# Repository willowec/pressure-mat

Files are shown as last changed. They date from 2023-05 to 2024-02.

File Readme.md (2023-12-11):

# Pressure Mat Project

This git repository contains all the code developed for the Electrical and Computer Engineering Capstone project of Evan Desmond and Willow Cunningham at the University of Maine, Orono. 

## The Mat

The pressure sensing mat uses the intersections between rows and columns of copper tape separated by velostat to form resistive pressure sensors. The mat has 28 rows and 56 columns, for a total of 1568 sensors at a resolution of 1cm^2.

## The PCB

Schematics for the PCB are in ```/board_kicad``` A render of the pcb is shown below.

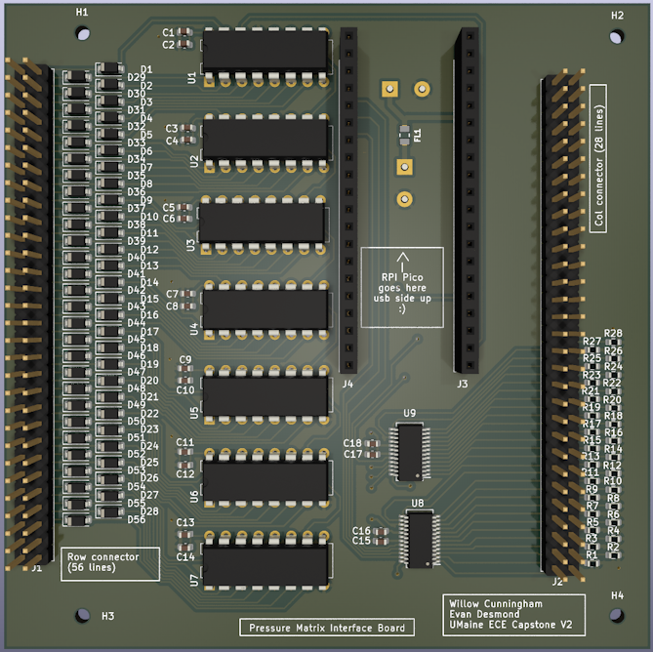
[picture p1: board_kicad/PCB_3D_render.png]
PCB 3D Render


## The Code

Code for the project is split into two primary parts: embedded side and host side.

### Embedded Code

The code that the RPI Pico runs is in the ```/board_code``` directory. It is responsible for controlling the ADCs and shift registers on the PCB in order to read the pressure sensors in the mat, and transmitting the mat data over USB serial to the connected host computer.

### Host Code

The python program in ```/GUI```  is used to view data recorded and transmitted by the interface board.

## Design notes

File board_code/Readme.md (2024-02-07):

# Board Side Code

This directory holds the embedded code that runs on the RPi Pico responsible for interfacing with the PMI PCB's ADC's and communicating with the connected laptop.

## Usage

The embedded code has three build targets: board_v1, board_v2, and board_v2_slow

 - board_v1.uf2: Designed to run on the v1 version of the PCB. single core, ~1Hz sample rate.
 - board_v2.uf2: Designed to run on the v2 version of the PCB. dual core, ~49Hz sample rate (rate limited by the computer's ability to handle serial communications).
 - board_v2_slow.uf2: Designed to run on the v2 version of the PCB. dual core, rate limited to ~8Hz sample rate.

### Build the code:
1. Install the rpi pico sdk somewhere on your computer: [pico-sdk](https://github.com/raspberrypi/pico-sdk)
2. Enter a linux environment (WSL)
3. 
        mkdir build
        cd build
        export PICO_SDK_PATH=../relative/path/to/the/cloned/directory/named/pico-sdk
        cmake ..
        make

4. Copy the uf2 file of the build target you want to program the pico with to the pico's flash to program it.

### Communicating With The Board

After connecting the programmed RPi Pico to your computer via usb, it can be talked to over serial. The board can understand the following commands:

1. PRINT_INFO:

    message:

        print_info
        
    response:

    The board prints a short message identifying its software version and then awaits further commands.

2. GET_CAL_VALS:

    message:

        get_cal_vals
        
    response:

    The board reads the mat in full once and transmits the collected data over serial before waiting for further commands. See [Mat Data Transmission Format](#mat-data-transmission-format) for more information.

3. START_READING:

    message:

        start_reading
        
    response:

    The board stops listening to commands and begins reading and transmitting sensor values over serial. The board will continue to read and transmit mat data until unpowered. See [Mat Data Transmission Format](#mat-data-transmission-format) for more information.

### Mat Data Transmission Format

The board code is designed to interface a 28x56 array of resistive pressure sensors, where data from each sensor is recorded by an 8-bit ADC. Each time the mat is read, 1,568 8-bit values must be transmitted over serial. This transmission is performed in accordance with the following format, where bytes 1-4 are the verification sequence and bytes 5-1572 are the values that the ADCs on the PCB recorded for each sensor:

        byte number:           1       2       3       4       5       6               1571    1572
        character value:       0xFF    0xFE    0xFE    0xFF    0xXX    0xXX    ...     0xXX    0xXX

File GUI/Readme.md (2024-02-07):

# GUI

The GUI for communicating with the PMI board. Developed for python 3.10.6.

A screenshot of the GUI loading a past session

## Usage

1. Install dependancies using the following command:

		pip install -r requirements.txt

2. Run the GUI app using python

		python GUI.py

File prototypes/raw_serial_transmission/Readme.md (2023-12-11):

# Prototype to test the feasability of sending raw data over serial

Instead of encoding data into hexadecimal for transmission from pico to pc, it should be possible to send raw data over serial. This directory is a prototype which tests that theory.

The result of this test is that yes, data can be transmitted over serial much more efficiently than by encoding to hexadecimal and decoding it on the reciever.

[https://datasheets.raspberrypi.com/pico/getting-started-with-pico.pdf](https://datasheets.raspberrypi.com/pico/getting-started-with-pico.pdf)

requires that the pico_sdk repository is cloned on your computer

## building:

    mkdir build
    cd build
    export PICO_SDK_PATH=../relative/path/to/the/cloned/directory/named/pico-sdk
    cmake ..
    make

Then just copy the UF2 file onto the pico's flash

## Running

Plug the pico into your pc, then run

    python reciever.py "COMX"

where COMX should be the com port your pico shows up on (COM1, COM2, COM3, etc)

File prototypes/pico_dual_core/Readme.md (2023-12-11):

# Custom multicore for RP2040

This is a small multicore library for the raspberry pi pico. It is heavily based on the built-in multicore library that is provided by the Raspberry Pi Foundation. This library is used by the embedded code for the pressure mat project in ```/board_code```.

Reference:

[https://datasheets.raspberrypi.com/pico/getting-started-with-pico.pdf](https://datasheets.raspberrypi.com/pico/getting-started-with-pico.pdf)

requires that the pico_sdk repository is cloned on your computer

## building:

    mkdir build
    cd build
    export PICO_SDK_PATH=../relative/path/to/the/cloned/directory/named/pico-sdk
    cmake ..
    make

Then just copy the UF2 file onto the pico's flash

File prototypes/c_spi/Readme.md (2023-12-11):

# C spi multicore

this is an example of running an spi client (slave) on one core and an spi controller (master) on the other core

[https://datasheets.raspberrypi.com/pico/getting-started-with-pico.pdf](https://datasheets.raspberrypi.com/pico/getting-started-with-pico.pdf)

requires that the pico_sdk repository is cloned onto your computer

spi tutorial: (page 152)
[https://datasheets.raspberrypi.com/pico/raspberry-pi-pico-c-sdk.pdf](https://datasheets.raspberrypi.com/pico/raspberry-pi-pico-c-sdk.pdf)

## hardware:

Connect the two spi cahnnels absed on the following image

image of a pico with the two spi channels connected

## building:

    mkdir build
    cd build
    export PICO_SD_PATH=../relative/path/to/the/cloned/directory/named/pico-sdk
    cmake ..
    make

Then just copy the UF2 file onto the pico's flash

## build error: wrong compiler

If you compile the project and get a ton of errors about assembly instructions not being recognized, it is likely because the wrong compiler is being used. To fix this, cd into build and remove CMakeCache.txt, then rebuild:

    cd build
    rm CMakeCache.txt
    cmake ..
    make

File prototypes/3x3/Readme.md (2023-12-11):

# 3x3 mat prototype using an RPI pico

## Usage
1. Flash the board using rshell https://github.com/dhylands/rshell or any other means  
```
>rshell
>cp board.py /pyboard/main.py
```
2. Unpower and re-connect the pico board to restart it
3. Run the host script using ```py .\host.py```
4. Enter the com port the pico is connected to and hit connect

## Schematic
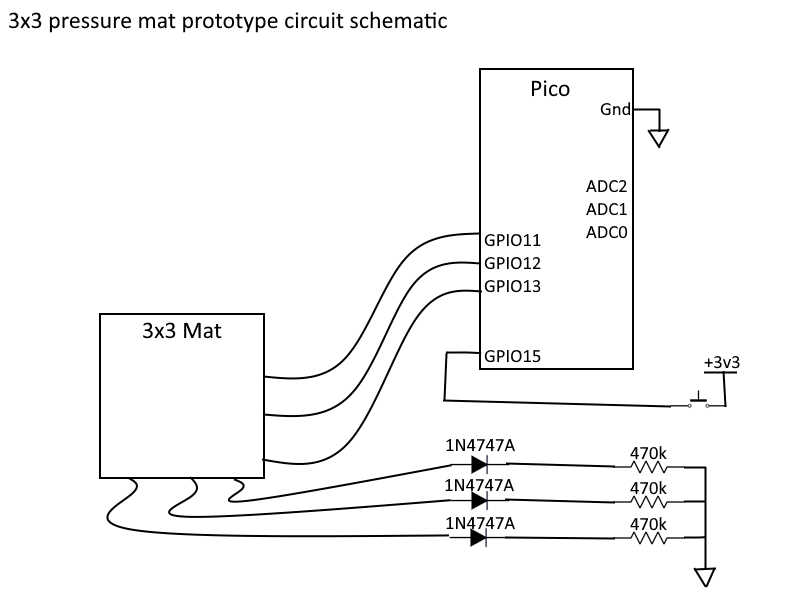
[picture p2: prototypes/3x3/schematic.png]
Overall Schematic


## Constructed Circuit
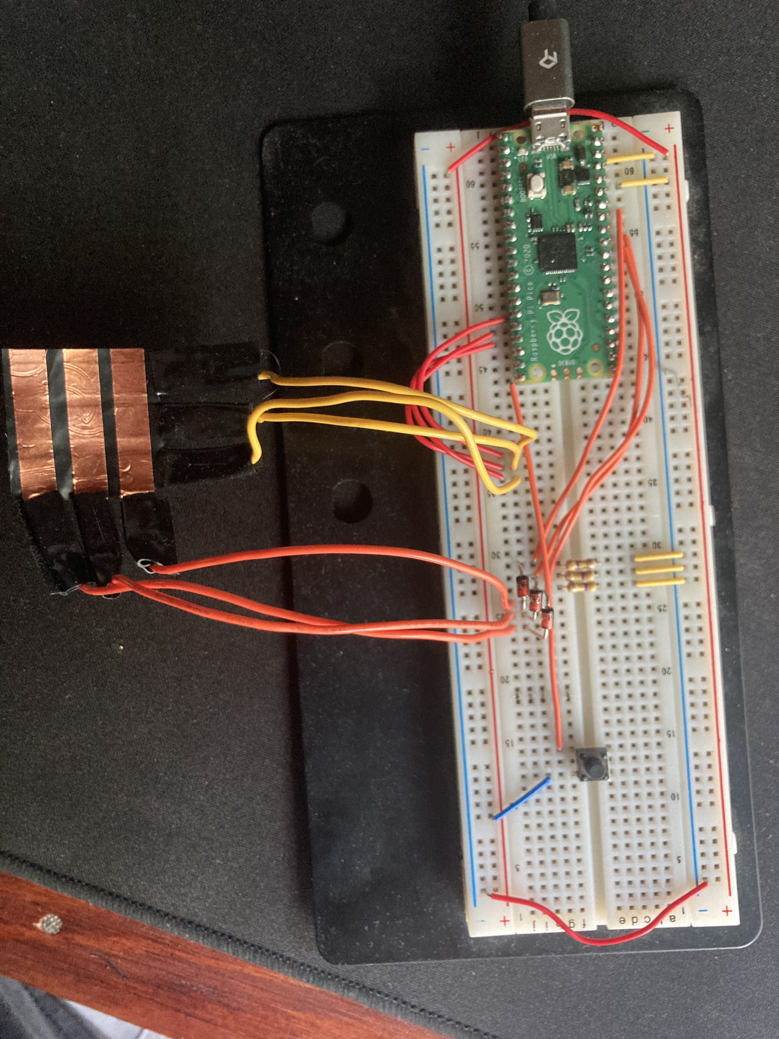
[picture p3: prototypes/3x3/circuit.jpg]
Photo of the circuit on a breadboard


## Programming the RPI Pico

Getting started (on Windows):

1. Download the micropython UF2 file from the RPI website and install it on the board:

    https://www.raspberrypi.com/documentation/microcontrollers/micropython.html

2. Install Rshell

### Copying code to the RPI Pico

1. run rshell:

    On my machine, the pico connects to COM3. You can find what port the pico is connected on by looking for it under the 'Ports (COM & LPT)' dropdown in the Device Manager on Windows

        rshell --buffer-size=512 -p COM3

2. in rshell, copy the python file that you want the pico to run to /pyboard/main.py

        cp pythonfile.py /pyboard/main.py

3. disconnect the pico from power and reconnect it. Your code should then run when the pi powers on.

## Resetting the RPI Pico

If you flash the pico with some code that takes permanent control of its serial port, you will need to clear the flash of the pico to reset it. A great example of code like this is the 3x3 prototype's [board.py file](./prototypes/3x3/board.py). Lets try to avoid writing code like this for the final project.

1. Download the flash_nuke UF2 file: [https://datasheets.raspberrypi.com/soft/flash_nuke.uf2](https://datasheets.raspberrypi.com/soft/flash_nuke.uf2)
2. Connect the pico to your laptop while holding the BOOTSEL button down
3. Copy the flask_nuke.uf2 file onto the pico storage device. This will reset its flash and reboot the pico. Do not disconnect power during this process.
4. Copy the micropython UF2 file onto the pico to re-flash it.

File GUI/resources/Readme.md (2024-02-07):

# PMI System Resources

This directory contains assorted scripts and resources used by the GUI for communicating with the PMI, and developers for collecting and plotting data from the PMI.

### averaged_calibration_curves.npy

[averaged_calibration_curves.npy](averaged_calibration_curves.npy) is a numpy array containing calibration curves to be loaded by the GUI program. The file is generated by [generate_cal_curves.py](generate_cal_curves.py).

### default_calibration_curves.npy

[default_calibration_curves.npy](default_calibration_curves.npy) is a numpy array containing calibration curves to be loaded by the GUI program. The file is generated by [generate_cal_curves.py](generate_cal_curves.py).

### calibrate_individual_sensor.py

[calibrate_individual_sensor.py](calibrate_individual_sensor.py) is a CLI tool for getting calibration data from a small number of sensors on the mat manually. This tool did not end up being used in the final version of the project.

### get_mat_data.py

[get_mat_data.py](get_mat_data.py) is a CLI tool used for collecting raw data from the PMI.

### generate_cal_curves.py

[generate_cal_curves.py](generate_cal_curves.py) generates caibration curves for the GUI based on data collected by [get_mat_data.py](get_mat_data.py).

### plot_readings.py

[plot_readings.py](plot_readings.py) produces various useful plots from the data collected by [get_mat_data.py](get_mat_data.py).

### test_matspeed.py

[test_matspeed.py](test_matspeed.py) tests the speed at which the PMI can collect and transmit data when the GUI is not slowing it down.

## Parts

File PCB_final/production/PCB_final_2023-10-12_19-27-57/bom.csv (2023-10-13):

Designator | Footprint | Quantity | Value | LCSC Part #
C1, C11, C13, C3, C5, C7, C9 | 603 | 7 | 1uF
C10, C12, C14, C17, C2, C4, C6, C8 | 603 | 8 | 0.1uF
C15, C16 | 603 | 2 | .1uF
D1, D10, D11, D12, D13, D14, D15, D16, D17, D18, D19, D2, D20, D21, D22, D23, D24, D25, D26, D27, D28, D29, D3, D30, D31, D32, D33, D34, D35, D36, D37, D38, D39, D4, D40, D41, D42, D43, D44, D45, D46, D47, D48, D49, D5, D50, D51, D52, D53, D54, D55, D56, D6, D7, D8, D9 | D_SOD-123 | 56 | MMSD4148
R1, R10, R11, R12, R13, R14, R15, R16, R17, R18, R19, R2, R20, R21, R22, R23, R24, R25, R26, R27, R28, R29, R3, R4, R5, R6, R7, R8, R9 | 603 | 29 | 100k
U10 | SOT-23-5 | 1 | LM321
U8, U9 | SSOP-24_3.9x8.7mm_P0.635mm | 2 | MAX11643EEG

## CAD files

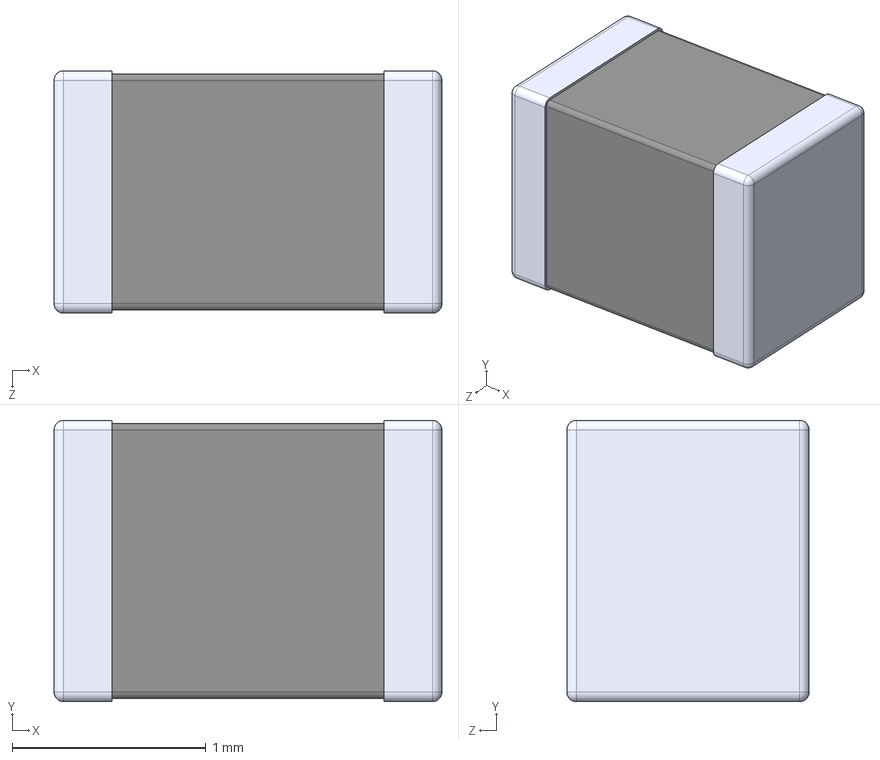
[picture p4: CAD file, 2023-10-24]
board_kicad/kicad_symbol_lib/BLM21BD272SN1L/BLM21BD272SN1L.step
2.00 x 1.45 x 1.25 mm

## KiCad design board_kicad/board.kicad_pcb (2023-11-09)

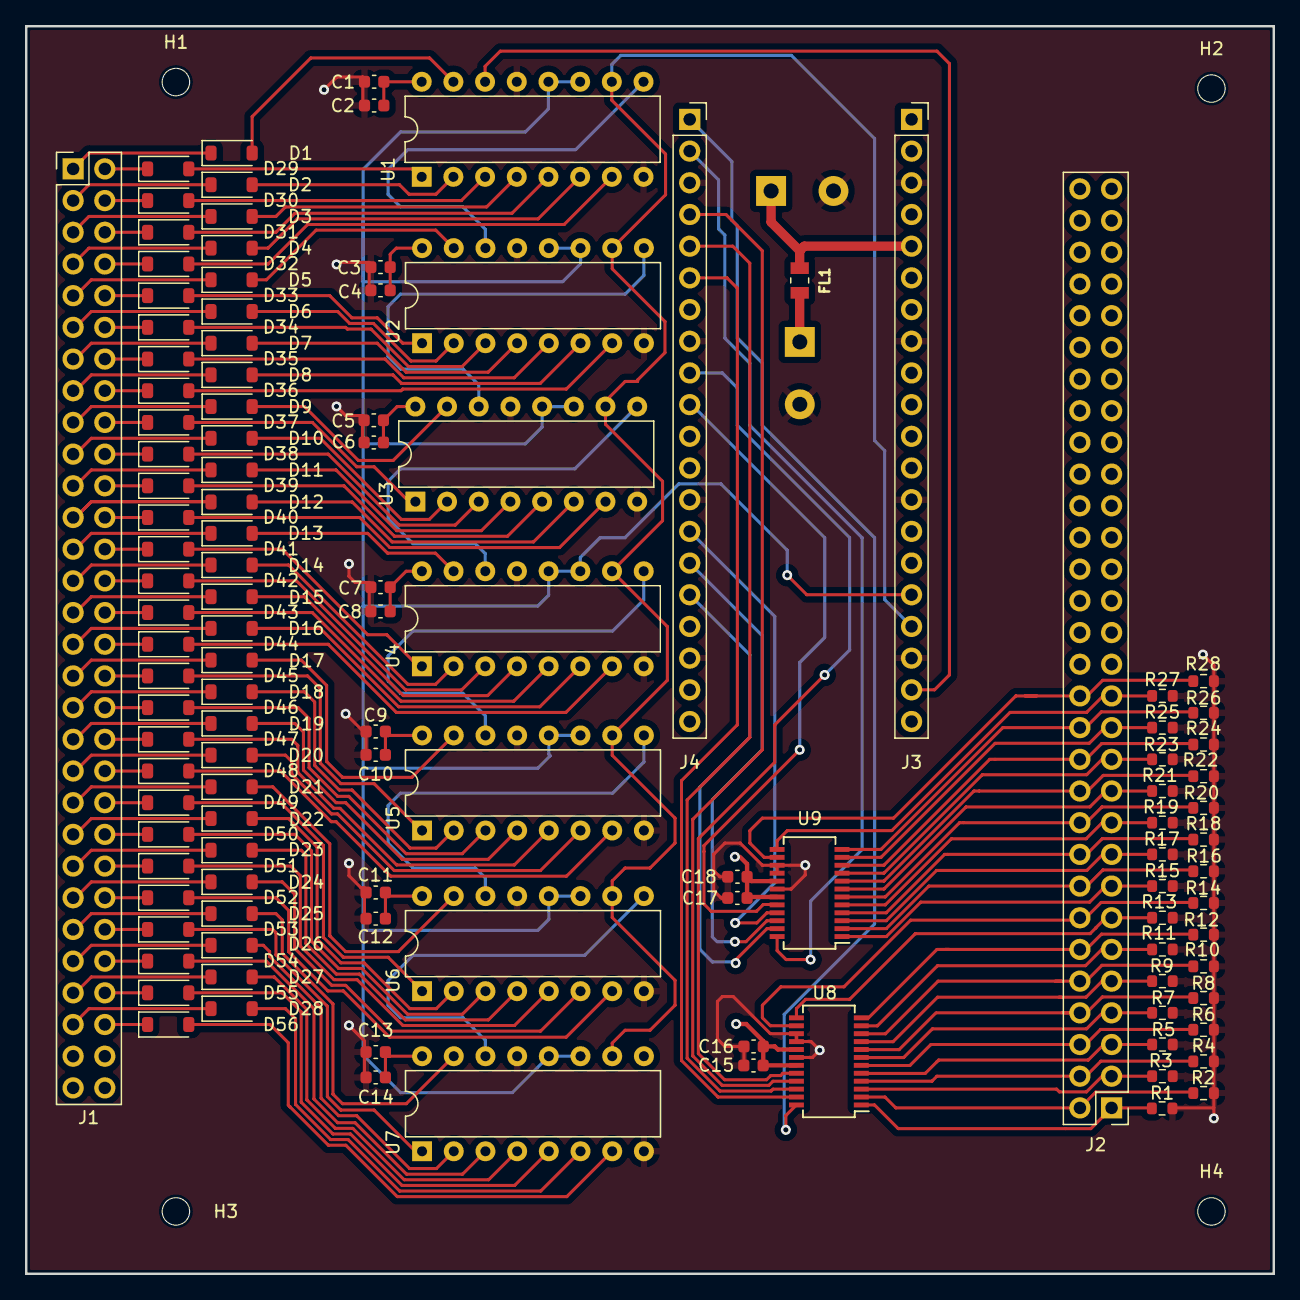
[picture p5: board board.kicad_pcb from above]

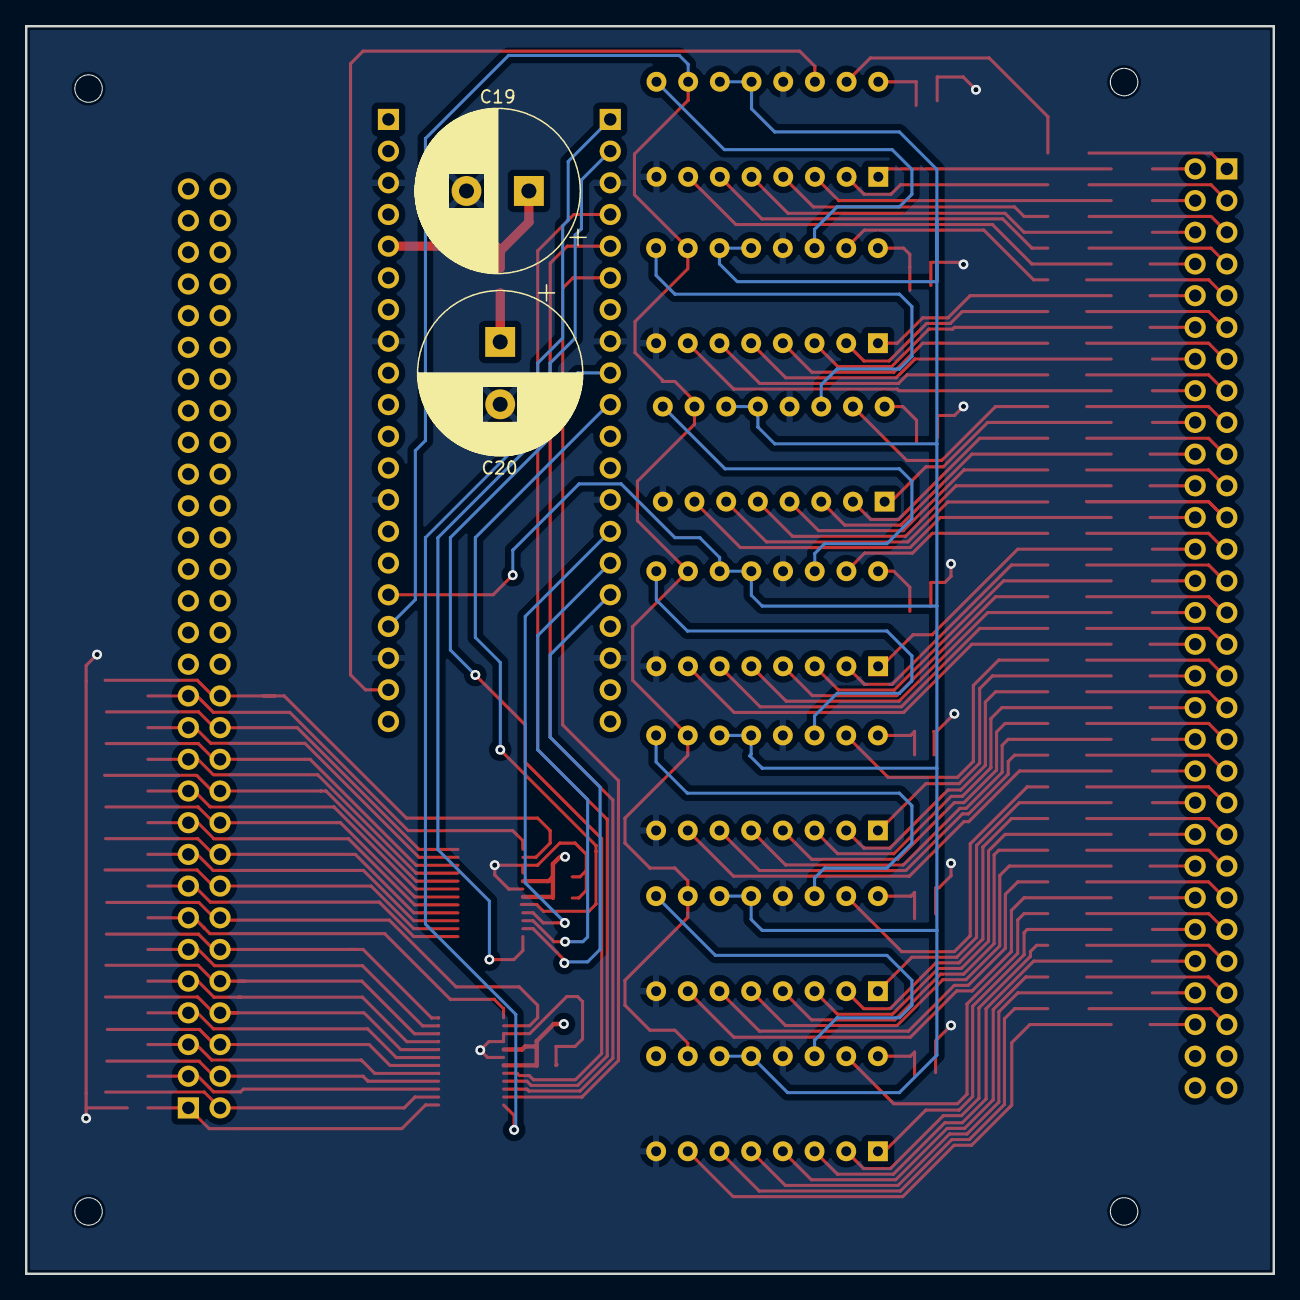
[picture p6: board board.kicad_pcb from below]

Board: 4 copper layers, 100.0 x 100.0 mm, 122 parts (2 on the bottom side), 162 nets.

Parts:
C1, C3, C5, C7, C9, C11, C13: 1uF; C_0603_1608Metric
C2, C4, C6, C8, C10, C12, C14: 0.1uF; C_0603_1608Metric
C15, C16, C17, C18: .1uF; C_0603_1608Metric
C19, C20: 4.7mF; CP_Radial_D13.0mm_P5.00mm
D1, D2, D3, D4, D5, D6, D7, D8, D9, D10, D11, D12, D13, D14, D15, D16, D17, D18, D19, D20, D21, D22, D23, D24, D25, D26, D27, D28, D29, D30, D31, D32, D33, D34, D35, D36, D37, D38, D39, D40, D41, D42, D43, D44, D45, D46, D47, D48, D49, D50, D51, D52, D53, D54, D55, D56: MMSD4148; D_SOD-123
FL1: BLM21BD272SN1L; BEADC2012X145N
H1, H2, H3, H4: MountingHole; MountingHole_2.2mm_M2
J1: 02x30_Shift_Register_Connector; PinHeader_2x30_P2.54mm_Vertical
J2: 02x30_ADC_Connector; PinHeader_2x30_P2.54mm_Vertical
J3: PicoPinSocketB; PinSocket_1x20_P2.54mm_Vertical
J4: PicoPinSocketA; PinSocket_1x20_P2.54mm_Vertical
R1, R2, R3, R4, R5, R6, R7, R8, R9, R10, R11, R12, R13, R14, R15, R16, R17, R18, R19, R20, R21, R22, R23, R24, R25, R26, R27, R28: 100k; R_0603_1608Metric
U1, U2, U3, U4, U5, U6, U7: 74HC595; DIP-16_W7.62mm
U8, U9: MAX11643EEG; SSOP-24_3.9x8.7mm_P0.635mm

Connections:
3V3_Pico: C19.1, FL1.1, J3.5
+3V3: C1.1, C2.1, C3.1, C4.1, C5.1, C6.1, C7.1, C8.1, C9.1, C10.1, C11.1, C12.1, C13.1, C14.1, C15.1, C16.1, C17.1, C18.1, C20.1, FL1.2, U1.16 (VCC), U2.16 (VCC), U3.16 (VCC), U4.16 (VCC), U5.16 (VCC), U6.16 (VCC), U7.16 (VCC), U8.17 (REF), U8.19 (VDD), U9.17 (REF), U9.19 (VDD)
/Interface Board/ADC1_EOC: J4.1, U8.24 (EOC)
/Interface Board/ADC2_EOC: J4.2, U9.24 (EOC)
/Interface Board/ADC_IN1: J2.1, R1.1, U8.1 (AIN0)
/Interface Board/ADC_IN2: J2.2, R2.1, U8.2 (AIN1)
/Interface Board/ADC_IN3: J2.3, R3.1, U8.3 (AIN2)
/Interface Board/ADC_IN4: J2.4, R4.1, U8.4 (AIN3)
/Interface Board/ADC_IN5: J2.5, R5.1, U8.5 (AIN4)
/Interface Board/ADC_IN6: J2.6, R6.1, U8.6 (AIN5)
/Interface Board/ADC_IN7: J2.7, R7.1, U8.7 (AIN6)
/Interface Board/ADC_IN8: J2.8, R8.1, U8.8 (AIN7)
/Interface Board/ADC_IN9: J2.9, R9.1, U8.9 (AIN8)
/Interface Board/ADC_IN10: J2.10, R10.1, U8.10 (AIN9)
/Interface Board/ADC_IN11: J2.11, R11.1, U8.11 (AIN10)
/Interface Board/ADC_IN12: J2.12, R12.1, U8.12 (AIN11)
/Interface Board/ADC_IN13: J2.13, R13.1, U8.13 (AIN12)
/Interface Board/ADC_IN14: J2.14, R14.1, U8.14 (AIN13)
/Interface Board/ADC_IN15: J2.15, R15.1, U9.1 (AIN0)
/Interface Board/ADC_IN16: J2.16, R16.1, U9.2 (AIN1)
/Interface Board/ADC_IN17: J2.17, R17.1, U9.3 (AIN2)
/Interface Board/ADC_IN18: J2.18, R18.1, U9.4 (AIN3)
/Interface Board/ADC_IN19: J2.19, R19.1, U9.5 (AIN4)
/Interface Board/ADC_IN20: J2.20, R20.1, U9.6 (AIN5)
/Interface Board/ADC_IN21: J2.21, R21.1, U9.7 (AIN6)
/Interface Board/ADC_IN22: J2.22, R22.1, U9.8 (AIN7)
/Interface Board/ADC_IN23: J2.23, R23.1, U9.9 (AIN8)
/Interface Board/ADC_IN24: J2.24, R24.1, U9.10 (AIN9)
/Interface Board/ADC_IN25: J2.25, R25.1, U9.11 (AIN10)
/Interface Board/ADC_IN26: J2.26, R26.1, U9.12 (AIN11)
/Interface Board/ADC_IN27: J2.27, R27.1, U9.13 (AIN12)
/Interface Board/ADC_IN28: J2.28, R28.1, U9.14 (AIN13)
/Interface Board/CS0: J4.9, U8.20 (CS)
/Interface Board/CS1: J4.10, U9.20 (CS)
/Interface Board/SER5: U4.9 (QH'), U5.14 (SER)
/Interface Board/SH_CLK: J3.16, U1.11 (SRCLK), U1.12 (RCLK), U2.11 (SRCLK), U2.12 (RCLK), U3.11 (SRCLK), U3.12 (RCLK), U4.11 (SRCLK), U4.12 (RCLK), U5.11 (SRCLK), U5.12 (RCLK), U6.11 (SRCLK), U6.12 (RCLK), U7.11 (SRCLK), U7.12 (RCLK)
/Interface Board/SH_CLR: J3.17, U1.10 (~SRCLR), U2.10 (~SRCLR), U3.10 (~SRCLR), U4.10 (~SRCLR), U5.10 (~SRCLR), U6.10 (~SRCLR), U7.10 (~SRCLR)
/Interface Board/SH_SERIN: J3.19, U1.14 (SER)
/Interface Board/SOUT1: D1.2 (A), U1.15 (QA)
/Interface Board/SOUT2: D29.2 (A), U1.1 (QB)
/Interface Board/SOUT3: D2.2 (A), U1.2 (QC)
/Interface Board/SOUT4: D30.2 (A), U1.3 (QD)
/Interface Board/SOUT5: D3.2 (A), U1.4 (QE)
/Interface Board/SOUT6: D31.2 (A), U1.5 (QF)
/Interface Board/SOUT7: D4.2 (A), U1.6 (QG)
/Interface Board/SOUT8: D32.2 (A), U1.7 (QH)
/Interface Board/SOUT9: D5.2 (A), U2.15 (QA)
/Interface Board/SOUT10: D33.2 (A), U2.1 (QB)
/Interface Board/SOUT11: D6.2 (A), U2.2 (QC)
/Interface Board/SOUT12: D34.2 (A), U2.3 (QD)
/Interface Board/SOUT13: D7.2 (A), U2.4 (QE)
/Interface Board/SOUT14: D35.2 (A), U2.5 (QF)
/Interface Board/SOUT15: D8.2 (A), U2.6 (QG)
/Interface Board/SOUT16: D36.2 (A), U2.7 (QH)
/Interface Board/SOUT17: D9.2 (A), U3.15 (QA)
/Interface Board/SOUT18: D37.2 (A), U3.1 (QB)
/Interface Board/SOUT19: D10.2 (A), U3.2 (QC)
/Interface Board/SOUT20: D38.2 (A), U3.3 (QD)
/Interface Board/SOUT21: D11.2 (A), U3.4 (QE)
/Interface Board/SOUT22: D39.2 (A), U3.5 (QF)
/Interface Board/SOUT23: D12.2 (A), U3.6 (QG)
/Interface Board/SOUT24: D40.2 (A), U3.7 (QH)
/Interface Board/SOUT25: D13.2 (A), U4.15 (QA)
/Interface Board/SOUT26: D41.2 (A), U4.1 (QB)
/Interface Board/SOUT27: D14.2 (A), U4.2 (QC)
/Interface Board/SOUT28: D42.2 (A), U4.3 (QD)
/Interface Board/SOUT29: D15.2 (A), U4.4 (QE)
/Interface Board/SOUT30: D43.2 (A), U4.5 (QF)
/Interface Board/SOUT31: D16.2 (A), U4.6 (QG)
/Interface Board/SOUT32: D44.2 (A), U4.7 (QH)
/Interface Board/SOUT33: D17.2 (A), U5.15 (QA)
/Interface Board/SOUT34: D45.2 (A), U5.1 (QB)
/Interface Board/SOUT35: D18.2 (A), U5.2 (QC)
/Interface Board/SOUT36: D46.2 (A), U5.3 (QD)
/Interface Board/SOUT37: D19.2 (A), U5.4 (QE)
/Interface Board/SOUT38: D47.2 (A), U5.5 (QF)
/Interface Board/SOUT39: D20.2 (A), U5.6 (QG)
/Interface Board/SOUT40: D48.2 (A), U5.7 (QH)
/Interface Board/SOUT41: D21.2 (A), U6.15 (QA)
/Interface Board/SOUT42: D49.2 (A), U6.1 (QB)
/Interface Board/SOUT43: D22.2 (A), U6.2 (QC)
/Interface Board/SOUT44: D50.2 (A), U6.3 (QD)
/Interface Board/SOUT45: D23.2 (A), U6.4 (QE)
/Interface Board/SOUT46: D51.2 (A), U6.5 (QF)
/Interface Board/SOUT47: D24.2 (A), U6.6 (QG)
/Interface Board/SOUT48: D52.2 (A), U6.7 (QH)
/Interface Board/SOUT49: D25.2 (A), U7.15 (QA)
/Interface Board/SOUT50: D53.2 (A), U7.1 (QB)
/Interface Board/SOUT51: D26.2 (A), U7.2 (QC)
/Interface Board/SOUT52: D54.2 (A), U7.3 (QD)
/Interface Board/SOUT53: D27.2 (A), U7.4 (QE)
/Interface Board/SOUT54: D55.2 (A), U7.5 (QF)
/Interface Board/SOUT55: D28.2 (A), U7.6 (QG)
/Interface Board/SOUT56: D56.2 (A), U7.7 (QH)
/Interface Board/SPI0_RX: J4.6, U8.23 (DOUT)
/Interface Board/SPI0_SCK: J4.4, U8.21 (SCLK)
/Interface Board/SPI0_TX: J4.5, U8.22 (DIN)
/Interface Board/SPI1_RX: J4.16, U9.23 (DOUT)
/Interface Board/SPI1_SCK: J4.14, U9.21 (SCLK)
/Interface Board/SPI1_TX: J4.15, U9.22 (DIN)
GND: C1.2, C2.2, C3.2, C4.2, C5.2, C6.2, C7.2, C8.2, C9.2, C10.2, C11.2, C12.2, C13.2, C14.2, C15.2, C16.2, C17.2, C18.2, C19.2, C20.2, J3.3, J3.8, J3.13, J3.18, J4.3, J4.8, J4.13, J4.18, R1.2, R2.2, R3.2, R4.2, R5.2, R6.2, R7.2, R8.2, R9.2, R10.2, R11.2, R12.2, R13.2, R14.2, R15.2, R16.2, R17.2, R18.2, R19.2, R20.2, R21.2, R22.2, R23.2, R24.2, R25.2, R26.2, R27.2, R28.2, U1.8 (GND), U1.13 (~OE), U2.8 (GND), U2.13 (~OE), U3.8 (GND), U3.13 (~OE), U4.8 (GND), U4.13 (~OE), U5.8 (GND), U5.13 (~OE), U6.8 (GND), U6.13 (~OE), U7.8 (GND), U7.13 (~OE), U8.15 (AIN14), U8.16 (AIN15), U8.18 (GND), U9.15 (AIN14), U9.16 (AIN15), U9.18 (GND)
unnamed: D1.1 (K), J1.1
unnamed: D2.1 (K), J1.3
unnamed: D3.1 (K), J1.5
unnamed: D4.1 (K), J1.7
unnamed: D5.1 (K), J1.9
unnamed: D6.1 (K), J1.11
unnamed: D7.1 (K), J1.13
unnamed: D8.1 (K), J1.15
unnamed: D9.1 (K), J1.17
unnamed: D10.1 (K), J1.19
unnamed: D11.1 (K), J1.21
unnamed: D12.1 (K), J1.23
unnamed: D13.1 (K), J1.25
unnamed: D14.1 (K), J1.27
unnamed: D15.1 (K), J1.29
unnamed: D16.1 (K), J1.31
unnamed: D17.1 (K), J1.33
unnamed: D18.1 (K), J1.35
unnamed: D19.1 (K), J1.37
unnamed: D20.1 (K), J1.39
unnamed: D21.1 (K), J1.41
unnamed: D22.1 (K), J1.43
unnamed: D23.1 (K), J1.45
unnamed: D24.1 (K), J1.47
unnamed: D25.1 (K), J1.49
unnamed: D26.1 (K), J1.51
unnamed: D27.1 (K), J1.53
unnamed: D28.1 (K), J1.55
unnamed: D29.1 (K), J1.2
unnamed: D30.1 (K), J1.4
unnamed: D31.1 (K), J1.6
unnamed: D32.1 (K), J1.8
unnamed: D33.1 (K), J1.10
unnamed: D34.1 (K), J1.12
unnamed: D35.1 (K), J1.14
unnamed: D36.1 (K), J1.16
unnamed: D37.1 (K), J1.18
unnamed: D38.1 (K), J1.20
unnamed: D39.1 (K), J1.22
unnamed: D40.1 (K), J1.24
unnamed: D41.1 (K), J1.26
unnamed: D42.1 (K), J1.28
unnamed: D43.1 (K), J1.30
unnamed: D44.1 (K), J1.32
unnamed: D45.1 (K), J1.34
unnamed: D46.1 (K), J1.36
unnamed: D47.1 (K), J1.38
unnamed: D48.1 (K), J1.40
unnamed: D49.1 (K), J1.42
unnamed: D50.1 (K), J1.44
unnamed: D51.1 (K), J1.46
unnamed: D52.1 (K), J1.48
unnamed: D53.1 (K), J1.50
unnamed: D54.1 (K), J1.52
unnamed: D55.1 (K), J1.54
unnamed: D56.1 (K), J1.56
unnamed: U1.9 (QH'), U2.14 (SER)
unnamed: U2.9 (QH'), U3.14 (SER)
unnamed: U3.9 (QH'), U4.14 (SER)
unnamed: U5.9 (QH'), U6.14 (SER)
unnamed: U6.9 (QH'), U7.14 (SER)

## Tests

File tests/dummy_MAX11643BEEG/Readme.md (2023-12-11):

# Dummy MAX1164BEEG

An approximation of the MAX1164BEEG ADC that runs on the rpi pico. This was used to test the embedded code of the pressure mat project during its early development.

## Usage

This program can run in two modes:
1. client/client mode, where both SPI0 and SPI1 host an instance of the fake ADC
2. controller/client mode, where the SPI0 channel simulates the ADC and the SPI1 channel communicates with it. Used primarily for ensuring that the ADC is being approximated correctly.

### Build the code:
1. 
        mkdir build
        cd build
        export PICO_SD_PATH=../relative/path/to/the/cloned/directory/named/pico-sdk
        cmake ..
        make

2. Copy the uf2 file to the pico's flash to program it

### Connect the pins

#### client/client mode (2 ADCs)
1. tie GP28 high to select client/client mode
2. ADC0 is available on SPI0:
    - GP2 is SCK
    - GP3 is TX
    - GP4 is RX
    - GP5 is CS
3. ADC1 is available on SPI1:
    - GP10 is SCK
    - GP11 is TX
    - GP12 is RX
    - GP13 is CS

#### controller/client mode (1 ADC)
1. tie GP28 low to select controller/client mode
2. to connect the controller to the client:
    1. connect GP2 to GP10
    2. connect GP3 to GP12
    3. connect GP4 to GP11
    4. connect GP5 to GP13

## Design

As a programmer working on the embedded systems code for the Pressure Sensing Matrix Mat project, I want a fake MAX11643BEEG ADC to use while deveoping embedded code so that I can begin development of the project while waiting for the real ADC chips to arrive.

Minimum viable product:

A C executable that runs on an rpi pico and

1. On core 1, acts as an SPI client which simulates the ADC:
    - must read and understand the input data byte for Setup and Conversion
    - conversion register must support scan mode 00

2. On core 2, acts as SPI controller which talks to the ADC:
    - must test all supported SPI operations and transmit results over UART to pc
    
Read the datasheet of the ADC for implementation details: [https://www.analog.com/media/en/technical-documentation/data-sheets/max11638-max11643.pdf](https://www.analog.com/media/en/technical-documentation/data-sheets/max11638-max11643.pdf)

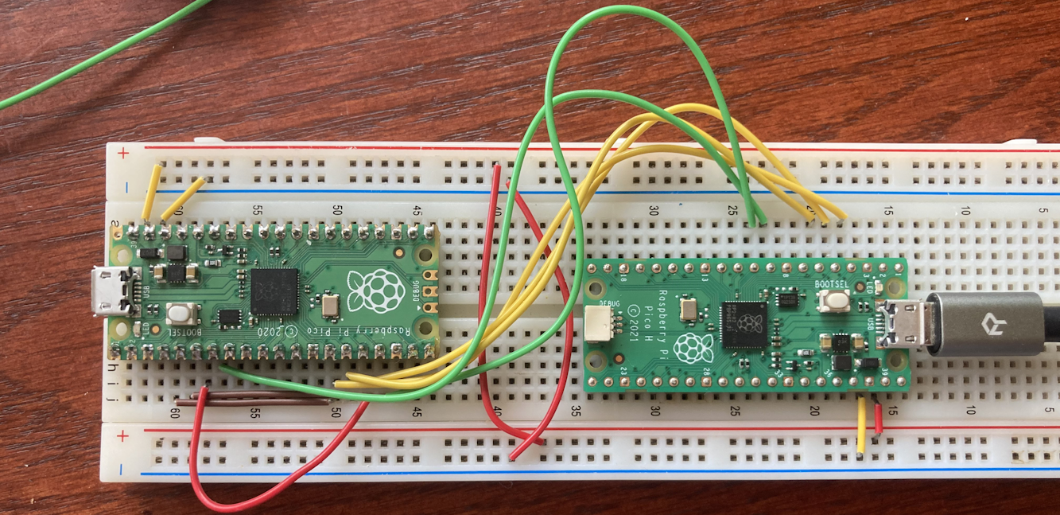
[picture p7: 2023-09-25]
tests/dummy_MAX11643BEEG/development_schem.png

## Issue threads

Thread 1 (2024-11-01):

Low pass pi filter capacitor

BerenChang, 2024-11-01:
Hey I wonder is c19 and c20 really 4.7 mF capacitors? I am trying to replicate your project. Those capacitors are really big and the pico board probably won’t fit on top of it. Does it make sense to have 4.7 uF capacitors instead? Thank you!

evlar416, 2024-11-05:
Hi, yes they were actually 4.7mF in order to reach the propper cutoff frequency for the filter. We found some low frequency noise on the power supply when using an oscilloscope so the filter was designed to reduce that.

Closed 2024-11-06.

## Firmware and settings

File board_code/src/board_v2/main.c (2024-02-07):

/*
main.c file for V2 of the RPi Pico of the PMI
*/

#include <stdio.h>
#include <stdlib.h>
#include "pico/stdlib.h"
#include "hardware/spi.h"
#include "hardware/gpio.h"
#include "pico/util/queue.h"

#include "transmitter.h"
#include "adc.h"
#include "matterface.h"
#include "custom_multicore.h"

#define LED_PIN         25

// The queue that passes data from core0 to core1 
queue_t queue;

int core1_main() {
    /*
    Core 1 handles transmitting the mat data to the connected computer in parallel with mat reads
    As data is recieved on the queue, send it over serial sequentially. Once a full mat read has been sent, send the verificaation sequence
    */  

    int i;
    struct queueItem temp;

    while (1) {
        for (i = 0; i < COL_HEIGHT; i++) {
            queue_remove_blocking(&queue, &temp);
            transmit_row(temp.row_data);
        }

        transmit_verification();
    }   

    return 1;   // should never exit
}


int main() {
    initialize_transmitter();

    // Delay with some LED blinking on startup
    gpio_init(LED_PIN);
    gpio_set_dir(LED_PIN, GPIO_OUT);
    for (int i = 0; i < 5; i++) {
        sleep_ms(100);
        gpio_put(LED_PIN, 0);
        sleep_ms(100);
        gpio_put(LED_PIN, 1);
    }

    // initialize the adcs 
    struct adc_inst *adc1 = malloc(sizeof(struct adc_inst));
    struct adc_inst *adc2 = malloc(sizeof(struct adc_inst));
    initialize_adcs(adc1, adc2, true);  // true for dual_channel mode

    // initialize the shift registers
    initialize_shreg_pins();

    // initialize the matterface End Of Conversion interrupts
    initialize_EOC_interrupts();

    // initialize the queue for passing data between the two cores
    queue_init(&queue, sizeof(item), COL_HEIGHT * 2);

    // start up the second core
    launch_core1((void *)core1_main);

    // Parse commands from the GUI before entering a session
	char input_string[256];
	uint32_t input_pointer, ch, parsed_command;
    while(1) {
        input_pointer = 0;
        while(1) {
            ch=getchar();
            if ((ch=='\n') || (ch=='\r')) {
                input_string[input_pointer]=0;
                break;
            }
			input_string[input_pointer]=ch;
			input_pointer++;
        }

        parsed_command = parse_input(input_string);
        if (parsed_command == START_READING_COMMAND_ID) {
            // break the input loop to move to the main loop and start reading the mat
            gpio_put(LED_PIN, 0);
            break;    
        }
        else if (parsed_command == GET_CAL_VALS_COMMAND_ID) {
            // perform one read of the mat and transmit it to the GUI
            read_mat(&queue, adc1, adc2);
        } 
        else if (parsed_command == PRINT_INFO_COMMAND_ID) {
            // print code info
            printf("This is PressureMat software for board v2!\n");
        } 
        else {
            printf("Unrecognized command\n");
        }
    }
    
    while (1) {
        // read the mat continuously until power-down
        read_mat(&queue, adc1, adc2);
    }

    return 1;   // should never exit
}

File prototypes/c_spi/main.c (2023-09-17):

/*

C SPI example
made with code from this digikey tutorial:
https://www.digikey.com/en/maker/projects/raspberry-pi-pico-rp2040-spi-example-with-micropython-and-cc/9706ea0cf3784ee98e35ff49188ee045

*/

#include <stdio.h>
#include "pico/stdlib.h"
#include "hardware/spi.h"
#include "hardware/gpio.h"
#include "pico/multicore.h"

#define LED_PIN         25

#define SPI0_SCK_PIN    2
#define SPI0_TX_PIN     3
#define SPI0_RX_PIN     4
#define SPI0_CSN_PIN    5
#define SPI1_SCK_PIN    10
#define SPI1_TX_PIN     11
#define SPI1_RX_PIN     12
#define SPI1_CSN_PIN    13

#define BUF_LEN         0x100

void printbuf(uint8_t buf[], size_t len) {
    int i;
    for (i = 0; i < len; i++) {
        if (i % 16 == 15)
            printf("%02x\n", buf[i]);
        else
            printf("%02x ", buf[i]);
    }

    // append trailing newline if one was missed
    if (i % 16) {
        putchar('\n');
    }
}

// main function for the second core
void core1_main() {
    printf("hello world from core 2\n");

    // initialize SPI1 as a controller
    spi_init(spi1, 1000000);  // clock at 1MHz
    gpio_set_function(SPI1_SCK_PIN, GPIO_FUNC_SPI);
    gpio_set_function(SPI1_TX_PIN, GPIO_FUNC_SPI);
    gpio_set_function(SPI1_RX_PIN, GPIO_FUNC_SPI);
    gpio_set_function(SPI1_CSN_PIN, GPIO_FUNC_SPI);

    uint8_t out_buf[BUF_LEN], in_buf[BUF_LEN];

    // Initialize the output buffer
    for (size_t i = 0; i < BUF_LEN; i++) {
        out_buf[i] = i;
    }

    for(size_t i = 0; ; i++) {
        printf("Reading/writing as controller\n");
        // write the buffer to MOSI, and read from MISO at the same time
        spi_write_read_blocking(spi1, out_buf, in_buf, BUF_LEN);
        //printf("read as controller:\n");
        //printbuf(in_buf, BUF_LEN);

        // sleep for a seconds
        sleep_ms(1000);
    }
}

int main() {
    stdio_init_all();

    gpio_init(LED_PIN);
    gpio_set_dir(LED_PIN, GPIO_OUT);
    // do a bit of a blinky
    for (int i = 0; i < 5; i++) {
        sleep_ms(500);
        gpio_put(LED_PIN, 0);
        sleep_ms(250);
        gpio_put(LED_PIN, 1);
    }

    multicore_launch_core1(core1_main);
    printf("hello world from core 1\n");

    // initialize SPI0 as a client
    spi_init(spi0, 1000000);  // clock at 1MHz
    spi_set_slave(spi0, true);
    gpio_set_function(SPI0_SCK_PIN, GPIO_FUNC_SPI);
    gpio_set_function(SPI0_TX_PIN, GPIO_FUNC_SPI);
    gpio_set_function(SPI0_RX_PIN, GPIO_FUNC_SPI);
    gpio_set_function(SPI0_CSN_PIN, GPIO_FUNC_SPI);

    uint8_t out_buf[BUF_LEN], in_buf[BUF_LEN];

    // initialize the output buffer
    for (size_t i = 0; i < BUF_LEN; i++) {
        out_buf[i] = ~i;
    }

    for (size_t i = 0; ; i++) {
        // Write the output to MISO, and at the same time read from MOSI
        printf("reading/writing as client\n");

        spi_write_read_blocking(spi0, out_buf, in_buf, BUF_LEN);

        
        // Write to stdio hatever came in from MOSI
        printf("Spi client says: read page %d from the MOSI line:\n", i);
        printbuf(in_buf, BUF_LEN);
    }
}

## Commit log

2023-05-28 Added short readme with info on the 3x3 prototype
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2023-09-04 Adding PCB files, only schematic has been edited and nothing else. Schematic is not connected yet either, just adding to repository for version control before continuing
    [PCB_no_rp2040.kicad_pcb, PCB_no_rp2040.kicad_sch]
2023-09-04 Added 4/7 shift registers and connected them to connection block, I believe this could be improved with bus lines
    [PCB_no_rp2040.kicad_sch]
2023-09-05 Added 7/7 shift registers with fully connected inputs and outputs, need to look into necesity of decoupling capacitor on GND
    [PCB_no_rp2040.kicad_sch]
2023-09-05 Added both ADC's connected all inputs that connect to the mat, but need to look into what other pins do before connecting them
    [PCB_no_rp2040.kicad_sch]
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2023-09-05 Changed all shift registers to be on the same SCLK, RCLK and OE. Also connected shift register 4 to 5 using node names
    [PCB_no_rp2040.kicad_sch]
2023-09-06 Turned all shift register outputs into nodes to make schematic cleaner and replaced old connectors w the actual 30x2 connector
    [PCB_no_rp2040.kicad_sch]
2023-09-06 used nodes to reconnect ADC's to new connectors and added voltage dividers to all ADC inputs
    [PCB_no_rp2040.kicad_sch]
2023-09-06 added diodes to between all shift register outputs and the connector
    [PCB_no_rp2040.kicad_sch]
2023-09-06 changed name of ADC connector, added box w text to voltage divider as visual aid
    [PCB_no_rp2040.kicad_sch]
2023-09-07 added decouple caps for the ADCs
    [PCB_no_rp2040.kicad_sch]
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2023-09-11 Created new folder for PCB with RP2040 included
    [PCB_final.kicad_pcb, PCB_final.kicad_sch]
2023-09-11 Separated RP2040 and interface board components into multiple sheets
    [PCB_final.kicad_sch, RP2040.kicad_sch, interface_board.kicad_sch]
2023-09-12 changed diodes to the correct surface mount diodes we will be using on the final pcb
    [RP2040.kicad_sch, interface_board.kicad_sch]
2023-09-12 changed all resistors to correct 100k value
    [RP2040.kicad_sch, interface_board.kicad_sch]
2023-09-12 beautified shift registers by putting decoupling capacitors as external elements and put in actual capacitor values
    [PCB_final.kicad_sch, RP2040.kicad_sch, interface_board.kicad_sch]
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2023-09-18 Mostly functional dummy ADC, spi breaks after transmitting too much
    [main.c]
2023-09-18 issue seems to be fixed
    [main.c]
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2023-09-19 Added active-low pass filter for power supply to schematic. Need to decide which OP AMP, resistor, and capacitor to use.
    [interface_board.kicad_sch]
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2023-09-19 Selected values for low-pass filter: C=0.1uF, R=500ohm, Fc=3.2kHz. Still need to select op amp, but we can probably go with whatever is readily available in parts cabinent
    [interface_board.kicad_sch]
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2023-09-20 Updated op amp and added rpi pico to schematic
    [interface_board.kicad_sch]
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2023-09-25 'Load past session' button now updates image on page but is not scaled correctly yet
    [GUI.py]
2023-09-25 Fixed issue in shift register connections
    [interface_board.kicad_sch]
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2023-10-02 fully connected, thermal pad errors
    [PCB_final.kicad_pcb]
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2023-10-02 fixed board edge
    [PCB_final.kicad_pcb]
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2023-10-03 Added error catching for reciever class so it does not quit the whole application if it encounters an error while trying to connect to the board
    [GUI.py]
2023-10-03 Started creating image saving to the correct index within the reciever class
    [GUI.py]
2023-10-07 Began mat interface code. Code-side ADC issues are all fixed.
    [adc.c, adc.h, main.c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]
2023-10-11 Swapped resistors on schematic from european to US
    [interface_board.kicad_sch]
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2023-10-12 PCB complete and redesigned w 4 layers. Passes desgin rule checker except for most of the silk screens. Schematic updated to connect adc unused pins to ground and beatified schematic
    [PCB_final.kicad_pcb, interface_board.kicad_sch]
2023-10-12 PCB silkscreen moved to stop warnings. Still getting a lot of seemingly unimportant errors from silkscreen. Updated design constraints to match manufacturer capabilities. Fixed a trace that was clipp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
    [PCB_final.kicad_pcb]
2023-10-12 Fixed all silkscreen warnings on PCB. Validated PCB. Added mounting holes to PCB.
    [PCB_final.kicad_pcb]
2023-10-12 Created directory for PCB fabrication files and populated it
    [BOM.csv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]
2023-10-13 Deleted manual PCB fab files and switched to JLCPCB plugin fab file output. Modified BOM and Positions files, removing the shift registers and pico pin headers. I suggest we also remove ribbon cable 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
    [BOM.csv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]
2023-10-13 Removed ribbon cable header pins from BOM and Positions files
    [bom.csv, positions.csv]
2023-10-15 Many caps on schematic were labeled c1 and c2 incorrectly. Swapped power supply filter to Pi filter, but with no value for L yet.
    [interface_board.kicad_sch]
2023-10-15 Fixed tpe hinting issue that prevented startup
    [GUI.py]
2023-10-15 Moved communcation with the mat to its own module. Many issues outstanding
    [GUI.py, communicator.py, host.py]
2023-10-16 Added MCP6001 as op-amp for low pass filter, fixed resistors that act as voltage dividers being named incorrectly
    [interface_board.kicad_sch]
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2023-10-16 Found naming errors with schematic and a few traces in PCB that weren't connected correctly. PCB now passes DRC with only a few warnings about silkscreen
    [PCB_final.kicad_pcb, interface_board.kicad_sch]
2023-10-16 Comms argely working. Issue where board fails early into first mat read
    [GUI.py, adc.c, communicator.py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]
2023-10-17 Moved active low pass op-amp filter to its own schematic sheet
    [PCB_final.kicad_sch, interface_board.kicad_sch, powerSupplyFilter.kicad_sch]
2023-10-17 Removed filter from schematic and PCB. Adjusted tracings on PCB and schematic for ADC inputs so that each ADC has 14 inputs
    [PCB_final.kicad_pcb, PCB_final.kicad_sch, interface_board.kicad_sch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]
2023-10-17 Removed old PCB production files and added new ones. Removed components from BOM and positions files that we are soldering ourselves
    [bom.csv, designators.csv, positions.csv]
2023-10-17 Fixed few traces on PCB that were not exactly correct
    [PCB_final.kicad_pcb, bom.csv, designators.csv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]
2023-10-19 board communcations are still flawed. Current im_array conversion is correct. Need to investigate fwrite
    [communicator.py]
2023-10-19 Chnaged comms to use hexadecimal. Issue now is that it seems to only be transmitting up a value 0-16
    [communicator.py, main.c]
2023-10-19 fixed issue with values being below 16
    [communicator.py]
2023-10-19 prettyprinting the array shows that the problem might be with tthe saving of the image
    [communicator.py]
2023-10-23 Fixed a lot of issues with the data transmission to the GUI, but data is still checkerboarded at source
    [communicator.py, main.c]
2023-10-24 investigating ADCS: changing channels_per_adc to 17 fixed patterns, but seems to have broken actual read
    [adc.h, main.c]
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2023-10-24 Using new info, fixed comms
    [main.c]
2023-10-24 Added files for ferrite bead used in schematic and pcb
    [BLM21BD272SN1L.step]
2023-10-24 Updated filter's ferrite bead and capacitors on schematic and PCB. Power supply filter now fully integrated
    [PCB_final.kicad_pcb, interface_board.kicad_sch, powerSupplyFilter.kicad_sch]
2023-10-30 Added note on pcb to indicate direction pico faces
    [PCB_final.kicad_pcb]
2023-10-30 odd commit, did the merge fail?
    [adc.c, adc.h, main.c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]
2023-10-31 temp fix eliminating ADC1 due to hardware failure
    [main.c, matterface.c]
2023-10-31 Added 2 bypass capacitors for VREF pins on ADCs on schematic. Placed caps on PCB and rerouted traces to pass DRC. Increased trace thickness for 3v3 on ADCs to 0.35mm and 0.75mm going from PICO 3v3 to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
    [PCB_final.kicad_pcb, interface_board.kicad_sch, powerSupplyFilter.kicad_sch]
2023-11-05 Using builtin ueue, not popping correctly
    [test.c]
2023-11-07 Updated kicad PCB to use both SPI channels of the RPI Pico
    [PCB_final.kicad_pcb, interface_board.kicad_sch, powerSupplyFilter.kicad_sch]
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2023-11-07 Fixed issue where first column of mat would be skipped by shregs
    [communicator.py, main.c, matterface.c]
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2023-11-07 Experiencing issue where mat shows same values for all columns
    [adc.c, main.c, matterface.c]
2023-11-08 Updated PCB for quality of life. Increased size to 100mmx100mm. Rotated pico 180 degrees. Aligned ribbon cable connectors. Moved silk screens to better locations. Moved mounting holes to better locat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
    [PCB_final.kicad_pcb]
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2023-11-14 Added a directory for gathered data and a tool for gathering it
    [matreading_0.0000pa.csv]
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2023-11-16 ZERO CURVE FIT FAILURES!!!!!!!
    [calibration.py]
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2023-11-16 plot_readings now calculates percentage error at max step size
    [plot_readings.py]
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2023-11-20 Added % error calculations to the stats box
    [GUI.py, calibration.py, mat_handler.py]
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2023-11-28 Adding a print statement within the busy loop of read_mat airquotes fixed the issue. Need to find workaround
    [matterface.c]
2023-11-28 Made reading_mat volatile to fix the issue. Duh...
    [matterface.c]
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2023-11-28 Moved GUI out of prototypes folder. Added PCB production files for PCB V2
    [bom.csv, designators.csv, matreading_0.0000pa.csv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]
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2023-11-29 Added experiment using putchar_raw() to skip conversion to headecimal
    [reciever.py, test.c, transmitter.h]
2023-11-30 Added error handling for the verification errors
    [communicator.py]
2023-11-30 Added number of errors tracking
    [communicator.py]
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2023-12-04 Added ability for individual calibrator to plot recorded data even if the curve fit fails
    [calibrate_individual_sensor.py, calibration.py]
2023-12-04 Fixed crash when - sign is in expected weight input
    [GUI.py]
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2023-12-05 renamed raw data to have pressure for individual sensors instead of full mat
    [matreading_0.0000000000pa.csv, matreading_0.0562037628pa.csv, matreading_0.0788191645pa.csv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]
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2023-12-05 Reworked cals to follow true Pa
    [calibration.py, generate_cal_curves.py]
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2023-12-06 Recalcualted pressure values. Previous names were assuming sensor area is 0.5cm2, actual value is 0.25cm2
    [matreading_0.0281018814pa.csv, matreading_0.0394095822pa.csv, matreading_0.0620249841pa.csv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]
2023-12-07 Regenerated cal curves based on sensor area fix
    [calibration.py, generate_cal_curves.py, mat_handler.py]
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2023-12-07 symbol lib fixes
    [board.kicad_sch, interface_board.kicad_sch, powerSupplyFilter.kicad_sch]
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2023-12-11 formatting improvements and rare division by zero fix
    [communicator.py, mat_handler.py]
2023-12-11 Fixed issue where CalSampleWorker was not actually sending get_cal_vals command
    [calibration.py, communicator.py]
